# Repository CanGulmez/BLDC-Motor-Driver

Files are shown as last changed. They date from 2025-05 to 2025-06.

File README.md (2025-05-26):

# 2kW BLDC Motor Driver

This project was created for Teknofest - Efficiency Challenge Competition

This repository consists of two part. First is the motor dirver firmware
and second is the KiCAD design. In firmware development, I've used VS Code
and PlatformIO plugin. PCB design is based on STM32F44RE microcontroller
so that the firmware was written with STM32 HAL (Hardware Abstraction Layer)
library. KiCAD design includes both schematic and PCB layout so that it 
can be used directly.

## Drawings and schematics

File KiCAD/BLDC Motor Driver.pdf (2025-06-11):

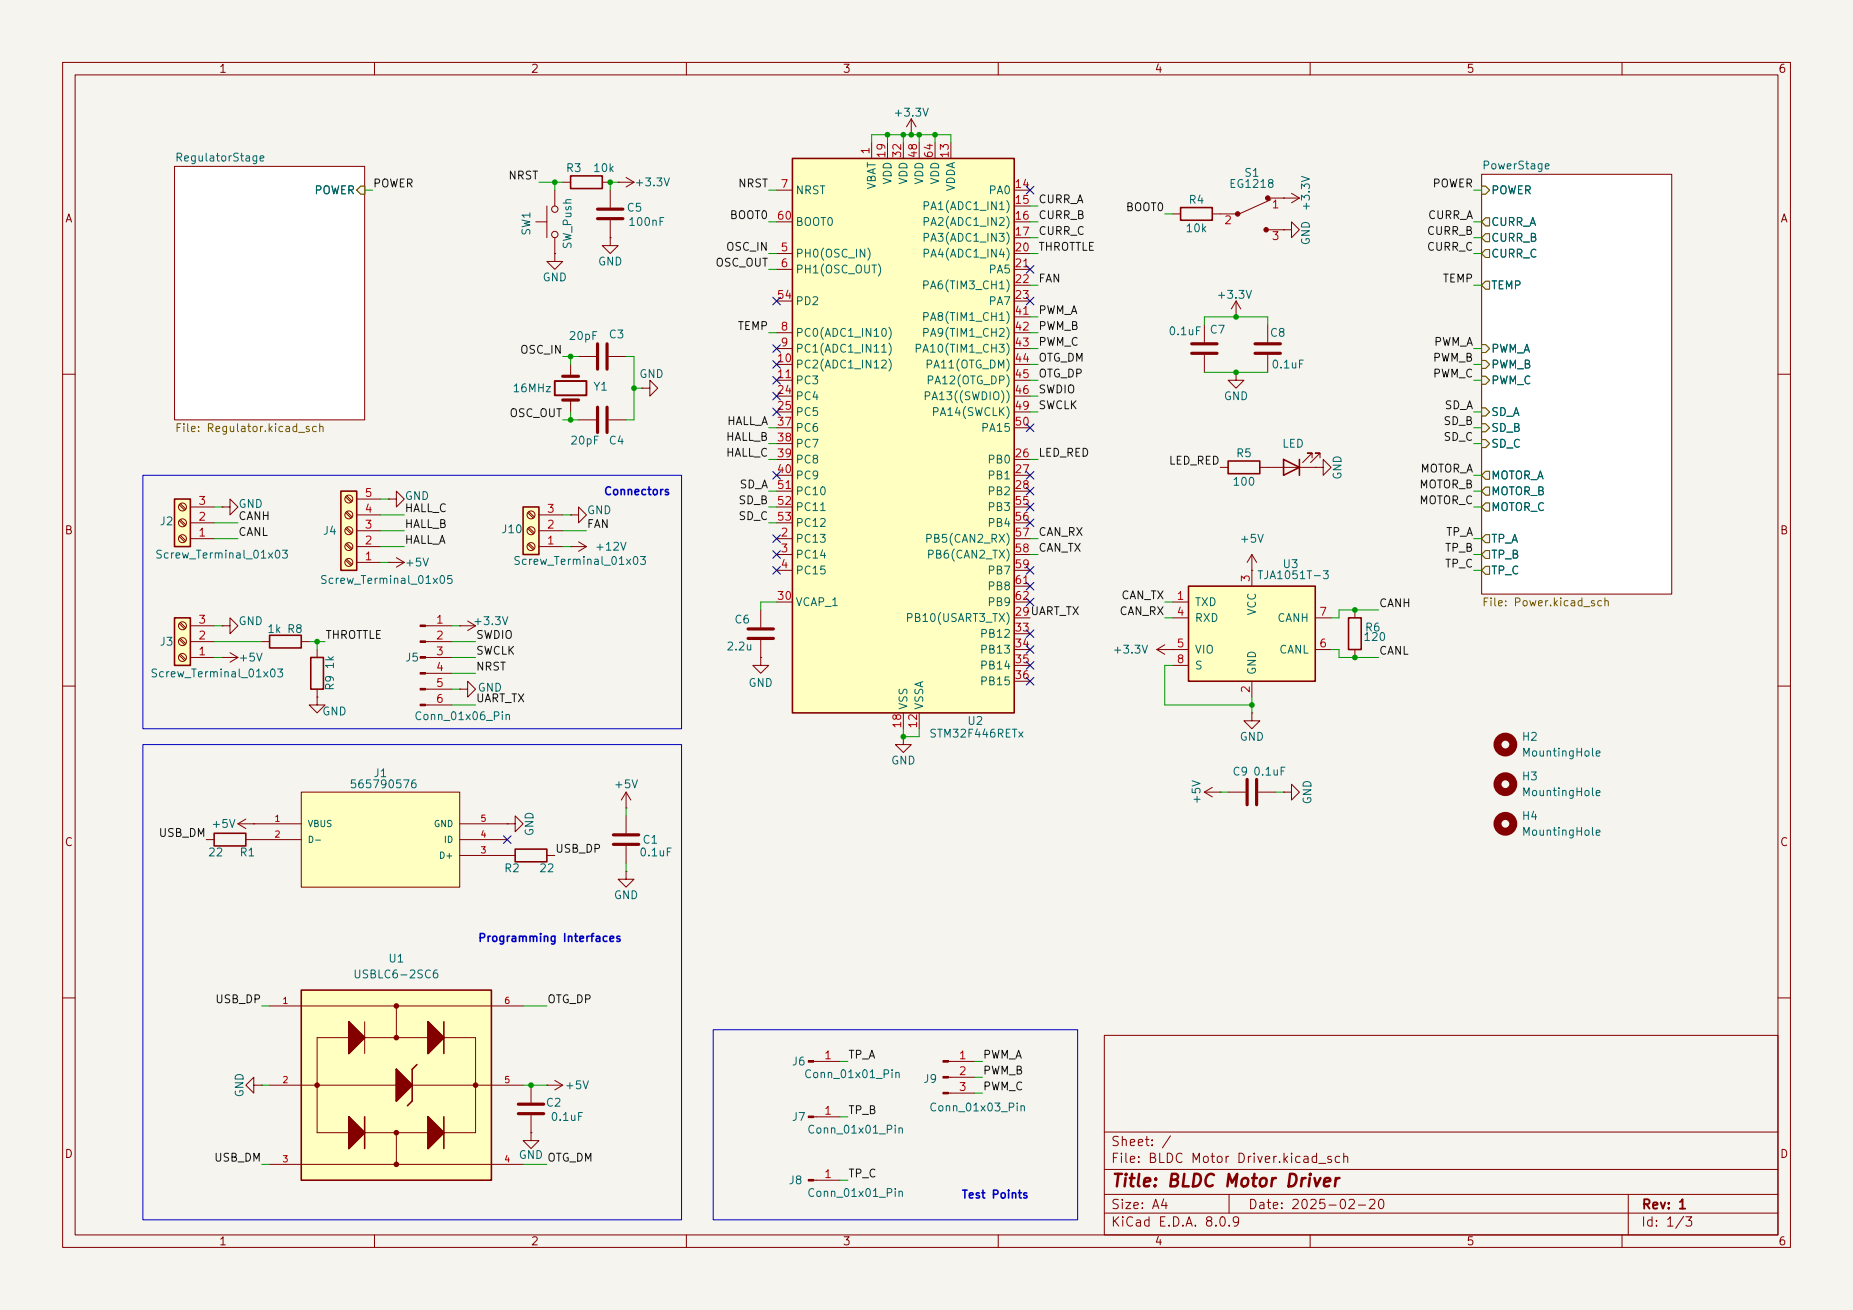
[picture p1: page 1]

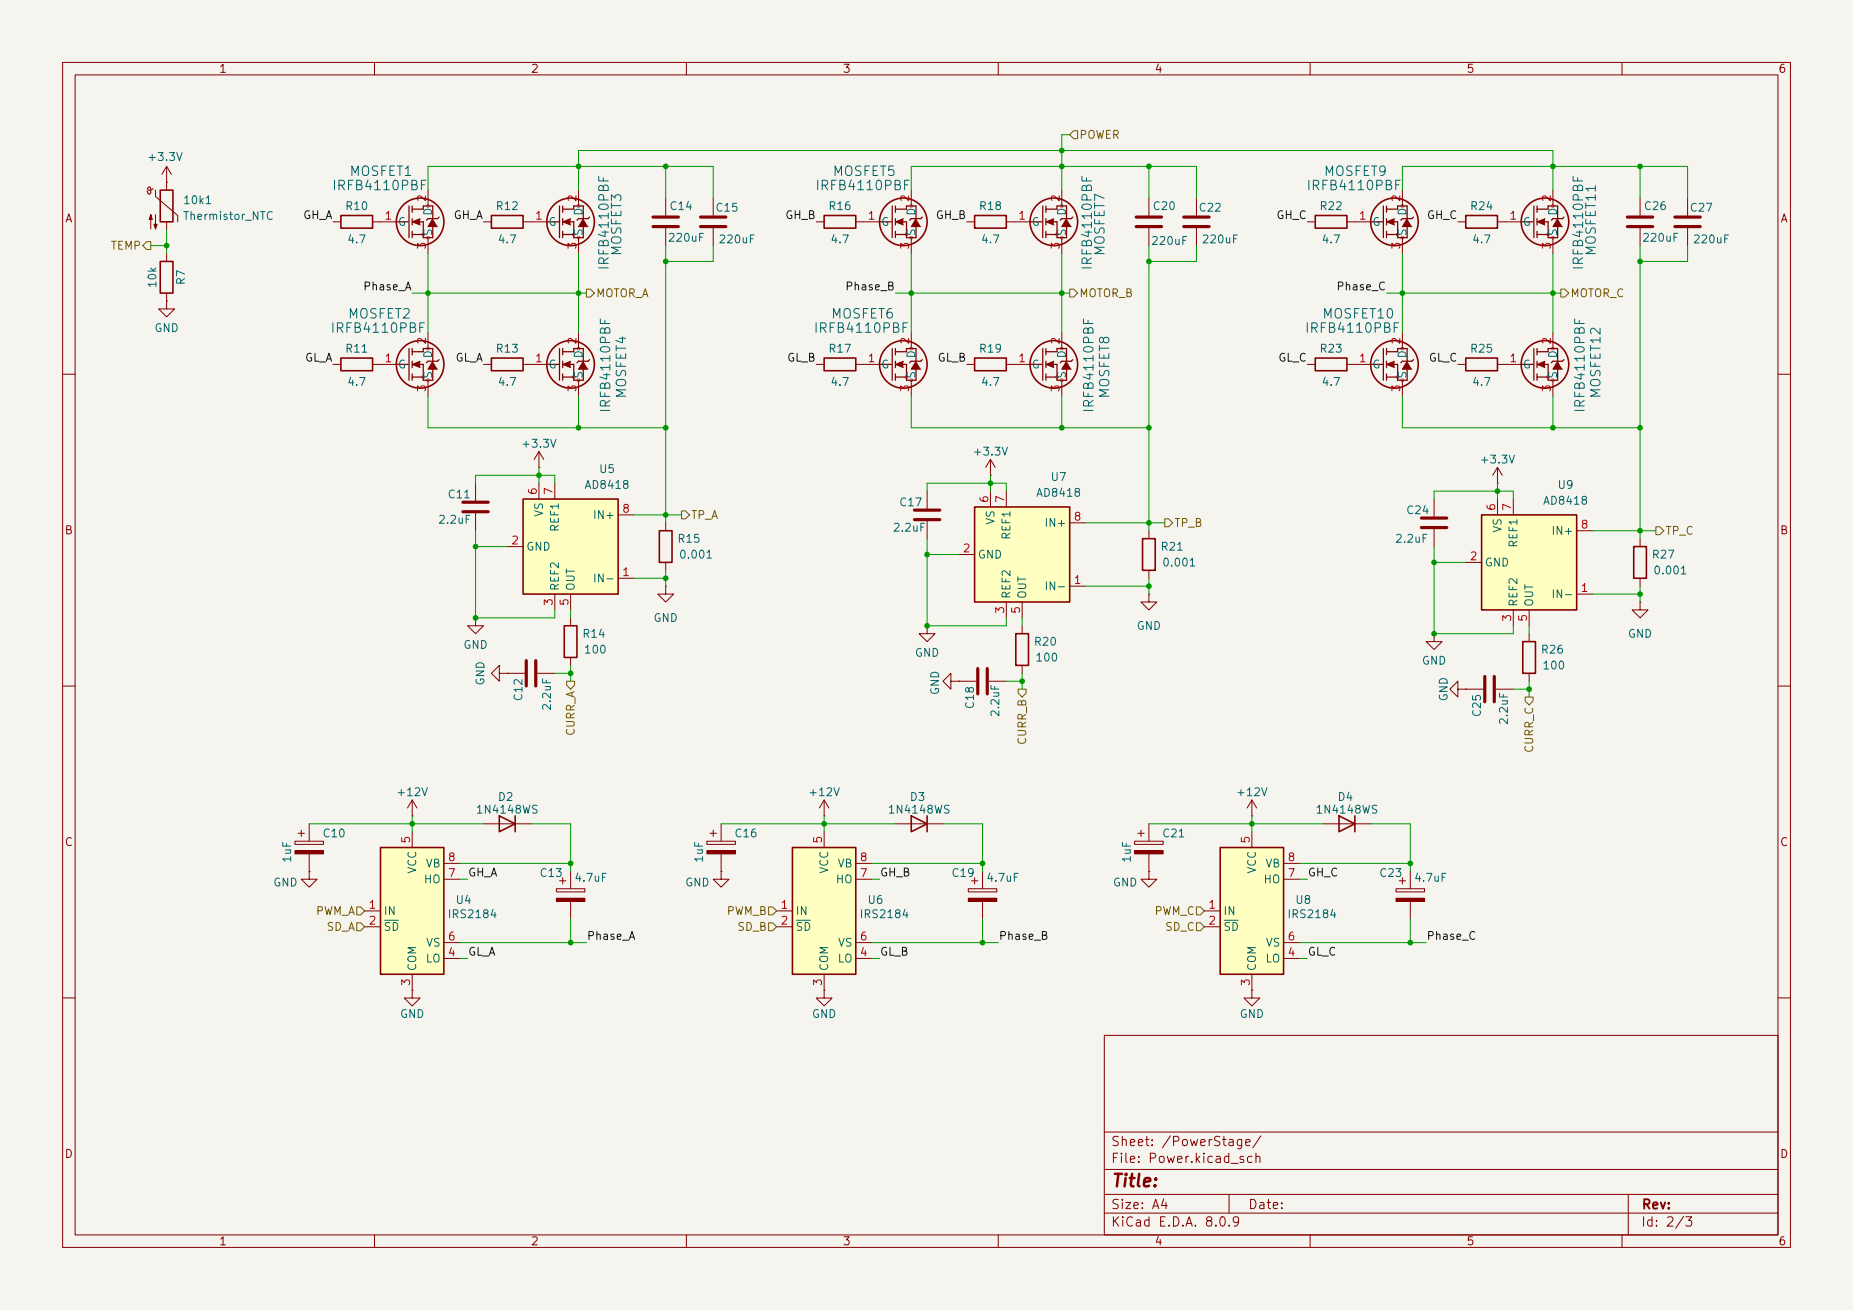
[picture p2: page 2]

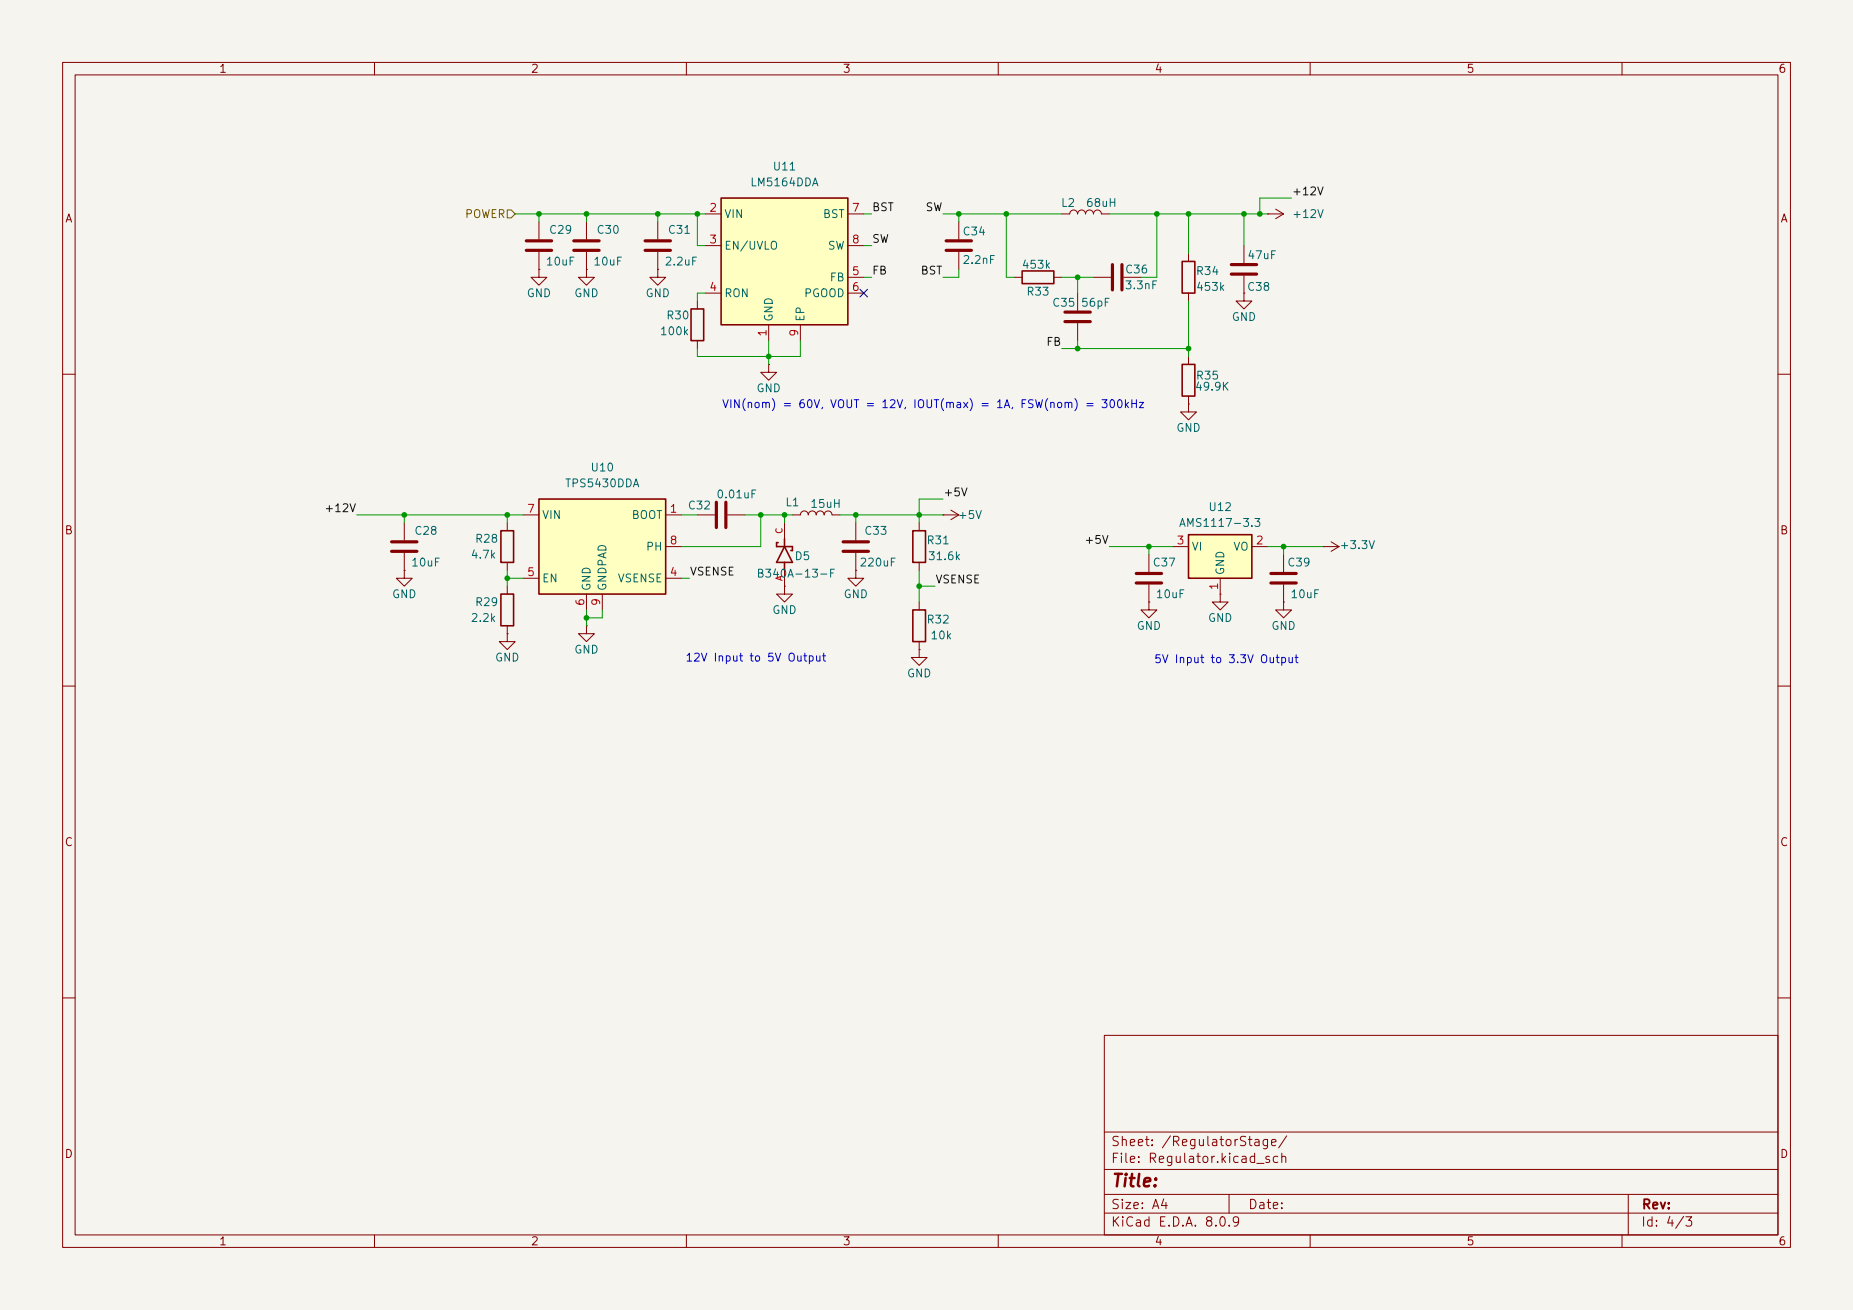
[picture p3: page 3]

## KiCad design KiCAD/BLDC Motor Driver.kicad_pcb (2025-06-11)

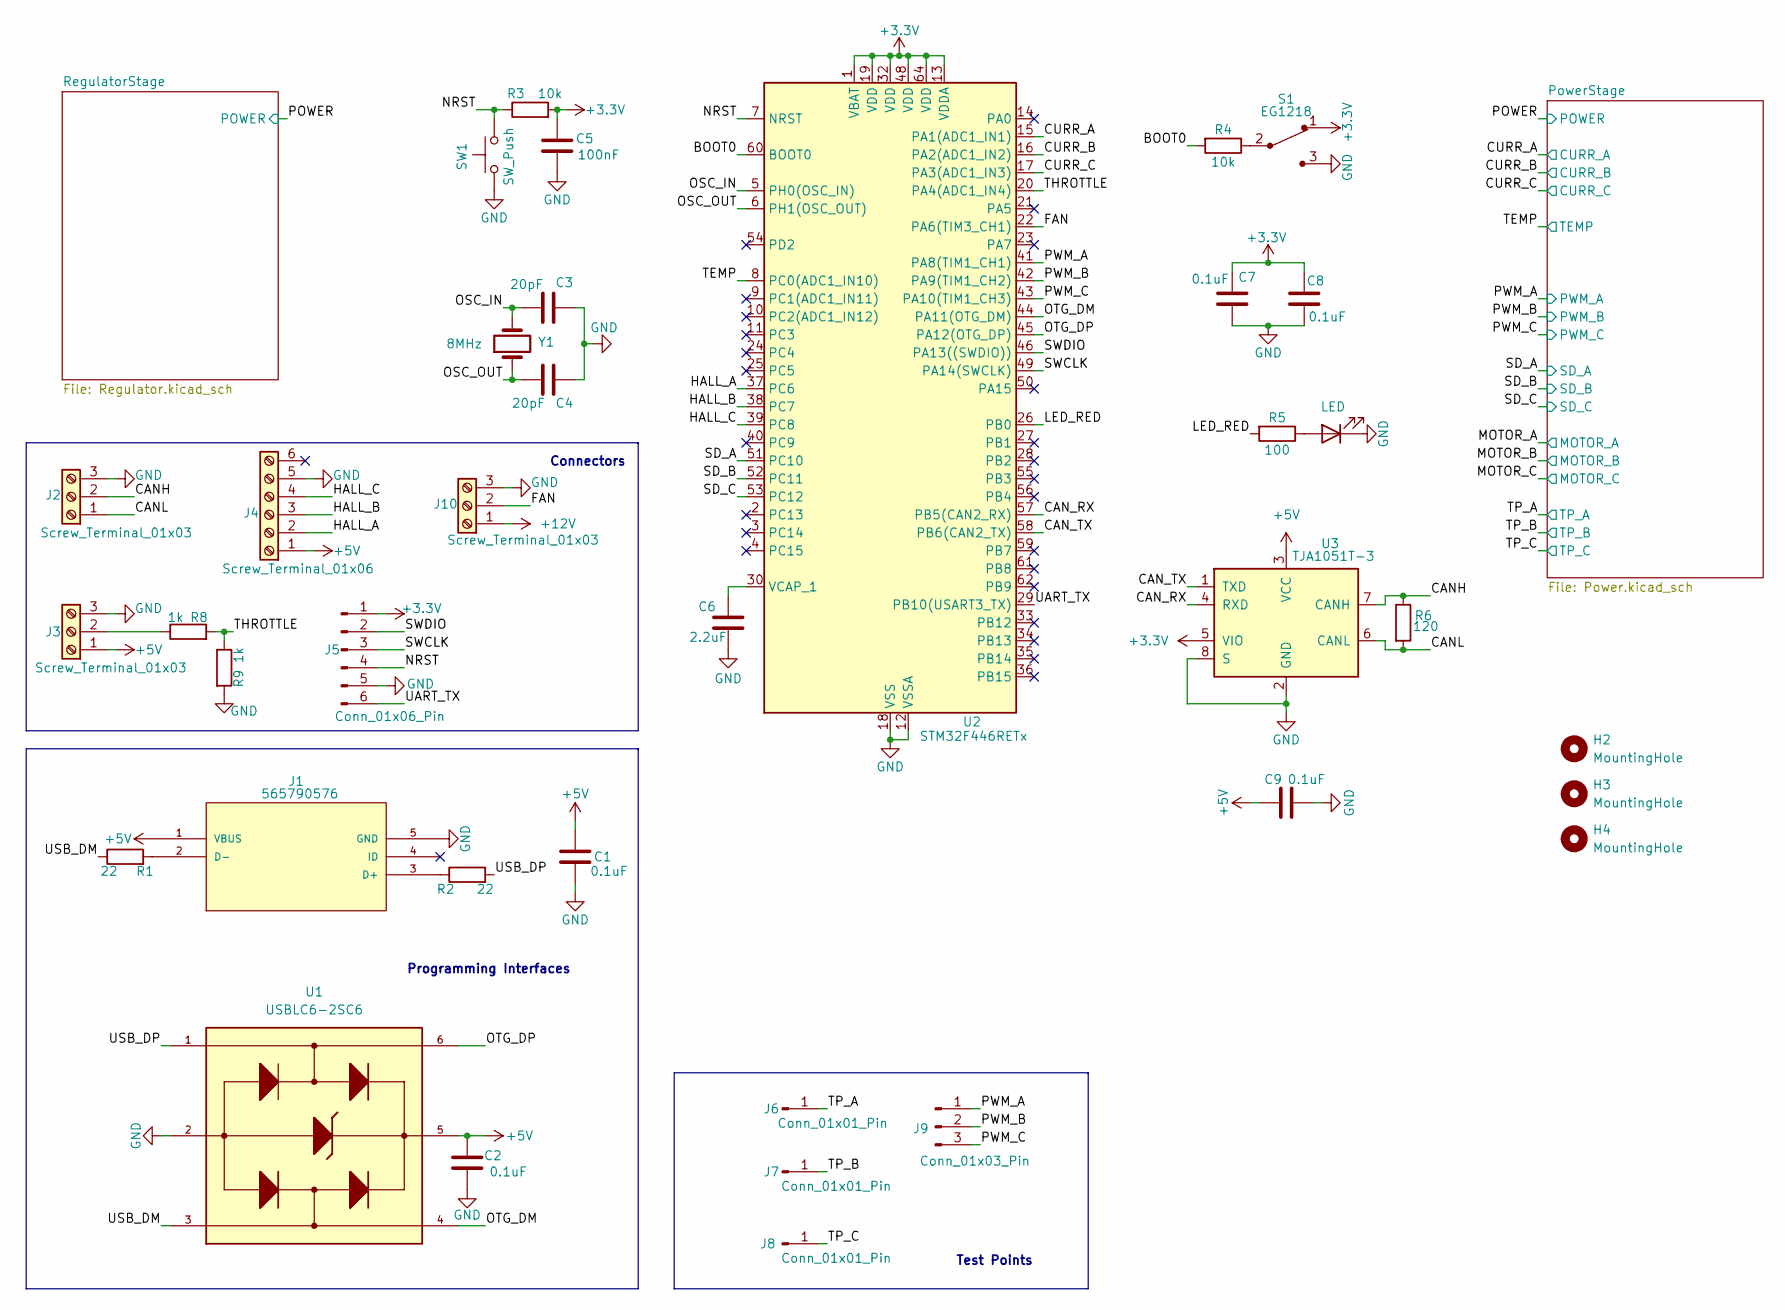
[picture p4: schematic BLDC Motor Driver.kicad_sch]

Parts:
C1, C2, C7, C8, C9: 0.1uF; C_0603_1608Metric
C3, C4: 20pF; C_0603_1608Metric
C5: 100nF; C_0603_1608Metric
C6: 2.2uF; C_0805_2012Metric
D1: LED; LED_0603_1608Metric
H2, H3, H4: MountingHole; MountingHole_3.2mm_M3
J1: 565790576; 56579-0576_MOL; MANUFACTURER_PART_NUMBER 565790576
J2, J3, J10: Screw_Terminal_01x03; TerminalBlock_Phoenix_MKDS-1,5-3-5.08_1x03_P5.08mm_Horizont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
J4: Screw_Terminal_01x06; TerminalBlock_Phoenix_MKDS-1,5-6-5.08_1x06_P5.08mm_Horizont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
J5: Conn_01x06_Pin; PinHeader_1x06_P2.54mm_Vertical
J6, J7, J8: Conn_01x01_Pin; PinHeader_1x01_P2.54mm_Vertical
J9: Conn_01x03_Pin; PinHeader_1x03_P2.54mm_Vertical
R1, R2: 22; R_0603_1608Metric
R3, R4: 10k; R_0603_1608Metric
R5: 100; R_0603_1608Metric
R6: 120; R_0603_1608Metric
R8, R9: 1k; R_0603_1608Metric
S1: EG1218; Switch_Slide_11.6x4mm_EG1218; MPN EG1218; Digi-Key_PN EG1903-ND
SW1: SW_Push; SW_SPST_B3U-1000P
U1: USBLC6-2SC6; SOT95P280X145-6N
U2: STM32F446RETx; LQFP-64_10x10mm_P0.5mm
U3: TJA1051T-3; SOIC-8_3.9x4.9mm_P1.27mm
Y1: 8MHz; Crystal_SMD_5032-2Pin_5.0x3.2mm

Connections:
+3.3V: C5.1, C7.1, C8.1, J5.1, R3.2, S1.1, U2.1 (VBAT), U2.13 (VDDA), U2.19 (VDD), U2.32 (VDD), U2.48 (VDD), U2.64 (VDD), U3.5 (VIO); also elsewhere on the board
+5V: C1.1, C2.1, C9.1, J1.1 (VBUS), J3.1, J4.1, U1.5, U3.3 (VCC); also elsewhere on the board
+12V: J10.1; also elsewhere on the board
/BOOT0: R4.2, U2.60 (BOOT0)
/CANH: J2.2, R6.1, U3.7 (CANH)
/CANL: J2.1, R6.2, U3.6 (CANL)
/CAN_RX: U2.57 (PB5(CAN2_RX)), U3.4 (RXD)
/CAN_TX: U2.58 (PB6(CAN2_TX)), U3.1 (TXD)
/CURR_A: U2.15 (PA1(ADC1_IN1)); also elsewhere on the board
/CURR_B: U2.16 (PA2(ADC1_IN2)); also elsewhere on the board
/CURR_C: U2.17 (PA3(ADC1_IN3)); also elsewhere on the board
/FAN: J10.2, U2.22 (PA6(TIM3_CH1))
/HALL_A: J4.2, U2.37 (PC6)
/HALL_B: J4.3, U2.38 (PC7)
/HALL_C: J4.4, U2.39 (PC8)
/LED_RED: R5.2, U2.26 (PB0)
/NRST: J5.4, R3.1, SW1.2, U2.7 (NRST)
/OSC_IN: C3.1, U2.5 (PH0(OSC_IN)), Y1.2
/OSC_OUT: C4.1, U2.6 (PH1(OSC_OUT)), Y1.1
/OTG_DM: U1.4, U2.44 (PA11(OTG_DM))
/OTG_DP: U1.6, U2.45 (PA12(OTG_DP))
/PWM_A: J9.1, U2.41 (PA8(TIM1_CH1)); also elsewhere on the board
/PWM_B: J9.2, U2.42 (PA9(TIM1_CH2)); also elsewhere on the board
/PWM_C: J9.3, U2.43 (PA10(TIM1_CH3)); also elsewhere on the board
/SD_A: U2.51 (PC10); also elsewhere on the board
/SD_B: U2.52 (PC11); also elsewhere on the board
/SD_C: U2.53 (PC12); also elsewhere on the board
/SWCLK: J5.3, U2.49 (PA14(SWCLK))
/SWDIO: J5.2, U2.46 (PA13((SWDIO)))
/TEMP: U2.8 (PC0(ADC1_IN10)); also elsewhere on the board
/THROTTLE: R8.2, R9.1, U2.20 (PA4(ADC1_IN4))
/TP_A: J6.1; also elsewhere on the board
/TP_B: J7.1; also elsewhere on the board
/TP_C: J8.1; also elsewhere on the board
/UART_TX: J5.6, U2.29 (PB10(USART3_TX))
/USB_DM: R1.1, U1.3
/USB_DP: R2.2, U1.1
GND: C1.2, C2.2, C3.2, C4.2, C5.2, C6.2, C7.2, C8.2, C9.2, D1.1 (K), J1.5 (GND), J2.3, J3.3, J4.5, J5.5, J10.3, R9.2, S1.3, SW1.1, U1.2, U2.12 (VSSA), U2.18 (VSS), U2.31 (VSS), U2.47 (VSS), U2.63 (VSS), U3.2 (GND), U3.8 (S); also elsewhere on the board
unnamed: D1.2 (A), R5.1
unnamed: J1.3 (D+), R2.1
unnamed: J1.2 (D-), R1.2
unnamed: J3.2, R8.1
unnamed: R4.1, S1.2
unnamed: C6.1, U2.30 (VCAP_1)

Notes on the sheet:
Connectors
Test Points
Programming Interfaces

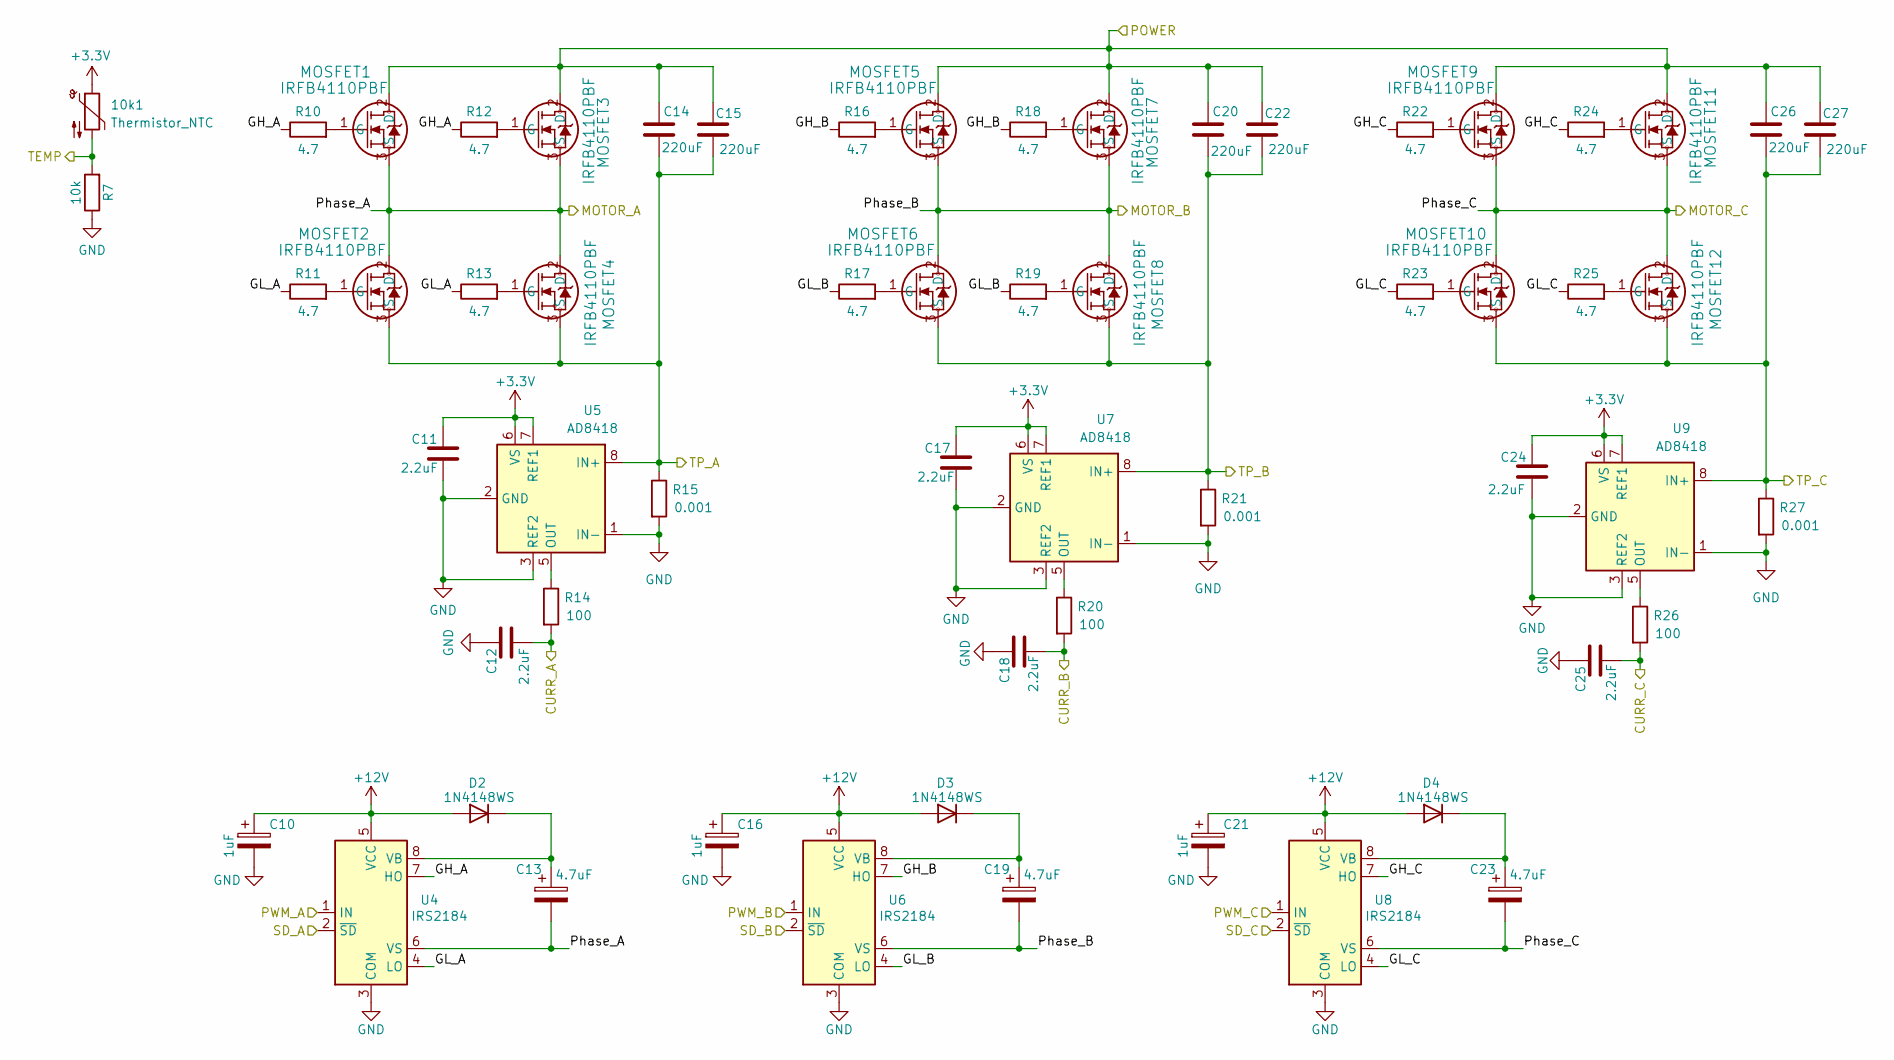
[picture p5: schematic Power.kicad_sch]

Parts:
10k1: Thermistor_NTC; R_0805_2012Metric
C10, C16, C21: 1uF; C_0805_2012Metric
C11, C12, C17, C18, C24, C25: 2.2uF; C_0805_2012Metric
C13, C19, C23: 4.7uF; C_0805_2012Metric
C14, C15, C20, C22, C26, C27: 220uF; C_Elec_10x10.2
D2, D3, D4: 1N4148WS; D_SOD-323
MOSFET1, MOSFET2, MOSFET3, MOSFET4, MOSFET5, MOSFET6, MOSFET7, MOSFET8, MOSFET9, MOSFET10, MOSFET11, MOSFET12: IRFB4110PBF; TO-220-3_Vertical
R7: 10k; R_0603_1608Metric
R10, R11, R12, R13, R16, R17, R18, R19, R22, R23, R24, R25: 4.7; R_0603_1608Metric
R14, R20, R26: 100; R_0603_1608Metric
R15, R21, R27: 0.001; R_2512_6332Metric
U4, U6, U8: IRS2184; SOIC-8_3.9x4.9mm_P1.27mm
U5, U7, U9: AD8418; SOIC-8_3.9x4.9mm_P1.27mm

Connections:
+3.3V: 10k1.1, C11.1, C17.1, C24.1, U5.6 (VS), U5.7 (REF1), U7.6 (VS), U7.7 (REF1), U9.6 (VS), U9.7 (REF1); also elsewhere on the board
+12V: C10.1, C16.1, C21.1, D2.2 (A), D3.2 (A), D4.2 (A), U4.5 (VCC), U6.5 (VCC), U8.5 (VCC); also elsewhere on the board
/CURR_A: C12.2, R14.2; also elsewhere on the board
/CURR_B: C18.2, R20.2; also elsewhere on the board
/CURR_C: C25.2, R26.2; also elsewhere on the board
/MOTOR_A: C13.2, MOSFET1.3 (S), MOSFET2.2 (D), MOSFET3.3 (S), MOSFET4.2 (D), U4.6 (VS)
/MOTOR_B: C19.2, MOSFET5.3 (S), MOSFET6.2 (D), MOSFET7.3 (S), MOSFET8.2 (D), U6.6 (VS)
/MOTOR_C: C23.2, MOSFET9.3 (S), MOSFET10.2 (D), MOSFET11.3 (S), MOSFET12.2 (D), U8.6 (VS)
/POWER: C14.1, C15.1, C20.1, C22.1, C26.1, C27.1, MOSFET1.2 (D), MOSFET3.2 (D), MOSFET5.2 (D), MOSFET7.2 (D), MOSFET9.2 (D), MOSFET11.2 (D); also elsewhere on the board
/PWM_A: U4.1 (IN); also elsewhere on the board
/PWM_B: U6.1 (IN); also elsewhere on the board
/PWM_C: U8.1 (IN); also elsewhere on the board
/PowerStage/GH_A: R10.1, R12.1, U4.7 (HO)
/PowerStage/GH_B: R16.1, R18.1, U6.7 (HO)
/PowerStage/GH_C: R22.1, R24.1, U8.7 (HO)
/PowerStage/GL_A: R11.1, R13.1, U4.4 (LO)
/PowerStage/GL_B: R17.1, R19.1, U6.4 (LO)
/PowerStage/GL_C: R23.1, R25.1, U8.4 (LO)
/SD_A: U4.2 (~SD); also elsewhere on the board
/SD_B: U6.2 (~SD); also elsewhere on the board
/SD_C: U8.2 (~SD); also elsewhere on the board
/TEMP: 10k1.2, R7.2; also elsewhere on the board
/TP_A: C14.2, C15.2, MOSFET2.3 (S), MOSFET4.3 (S), R15.1, U5.8 (IN+); also elsewhere on the board
/TP_B: C20.2, C22.2, MOSFET6.3 (S), MOSFET8.3 (S), R21.1, U7.8 (IN+); also elsewhere on the board
/TP_C: C26.2, C27.2, MOSFET10.3 (S), MOSFET12.3 (S), R27.1, U9.8 (IN+); also elsewhere on the board
GND: C10.2, C11.2, C12.1, C16.2, C17.2, C18.1, C21.2, C24.2, C25.1, R7.1, R15.2, R21.2, R27.2, U4.3 (COM), U5.1 (IN-), U5.2 (GND), U5.3 (REF2), U6.3 (COM), U7.1 (IN-), U7.2 (GND), U7.3 (REF2), U8.3 (COM), U9.1 (IN-), U9.2 (GND), U9.3 (REF2); also elsewhere on the board
unnamed: C13.1, D2.1 (K), U4.8 (VB)
unnamed: C19.1, D3.1 (K), U6.8 (VB)
unnamed: C23.1, D4.1 (K), U8.8 (VB)
unnamed: MOSFET1.1 (G), R10.2
unnamed: MOSFET2.1 (G), R11.2
unnamed: MOSFET3.1 (G), R12.2
unnamed: MOSFET4.1 (G), R13.2
unnamed: MOSFET5.1 (G), R16.2
unnamed: MOSFET6.1 (G), R17.2
unnamed: MOSFET7.1 (G), R18.2
unnamed: MOSFET8.1 (G), R19.2
unnamed: MOSFET9.1 (G), R22.2
unnamed: MOSFET10.1 (G), R23.2
unnamed: MOSFET11.1 (G), R24.2
unnamed: MOSFET12.1 (G), R25.2
unnamed: R14.1, U5.5 (OUT)
unnamed: R20.1, U7.5 (OUT)
unnamed: R26.1, U9.5 (OUT)

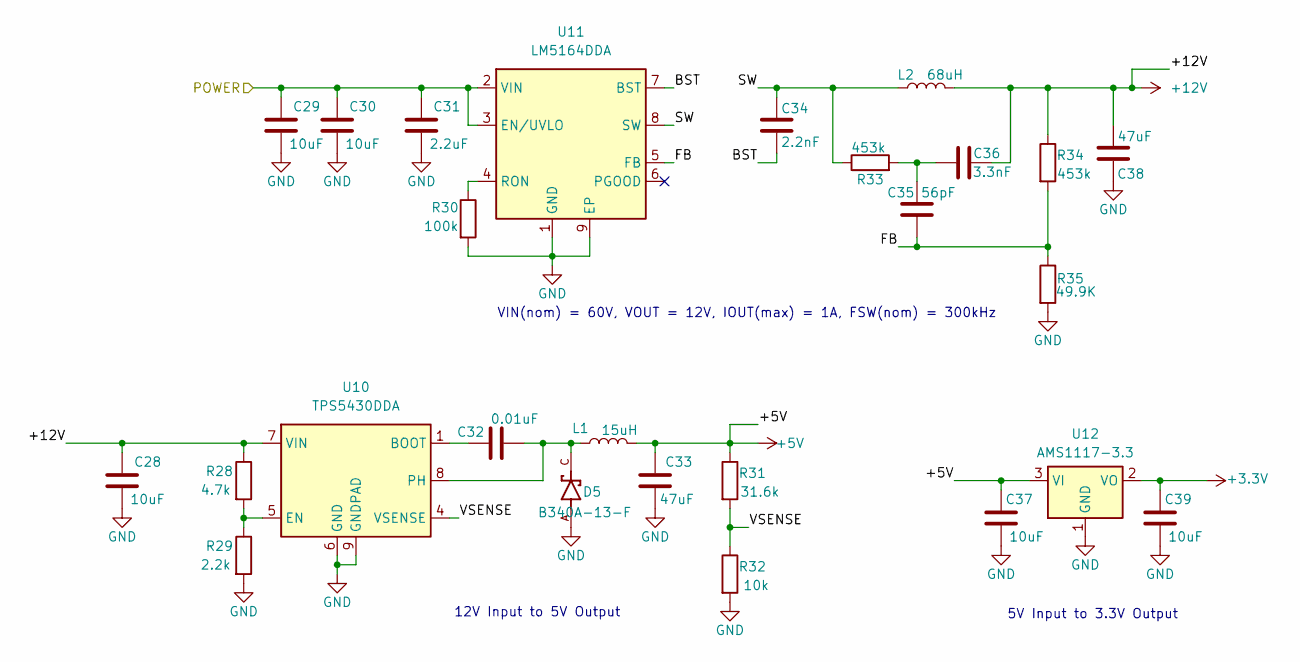
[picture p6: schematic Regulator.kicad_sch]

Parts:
C28, C29, C30, C37, C39: 10uF; C_0805_2012Metric
C31: 2.2uF; C_0805_2012Metric
C32: 0.01uF; C_0402_1005Metric
C33, C38: 47uF; C_Elec_6.3x5.4
C34: 2.2nF; C_0402_1005Metric
C35: 56pF; C_0402_1005Metric
C36: 3.3nF; C_0402_1005Metric
D5: B340A-13-F; DIOM5226X240N; PARTREV 17-2
L1: 15uH; L_0805_2012Metric
L2: 68uH; L_0805_2012Metric
R28: 4.7k; R_0603_1608Metric
R29: 2.2k; R_0603_1608Metric
R30: 100k; R_0603_1608Metric
R31: 31.6k; R_0603_1608Metric
R32: 10k; R_0603_1608Metric
R33, R34: 453k; R_0603_1608Metric
R35: 49.9K; R_0603_1608Metric
U10: TPS5430DDA; TI_SO-PowerPAD-8_ThermalVias
U11: LM5164DDA; HSOP-8-1EP_3.9x4.9mm_P1.27mm_EP2.41x3.1mm_ThermalVias
U12: AMS1117-3.3; SOT-223-3_TabPin2

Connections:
+3.3V: C39.1, U12.2 (VO); also elsewhere on the board
+5V: C33.1, C37.1, L1.2, R31.1, U12.3 (VI); also elsewhere on the board
+12V: C28.1, C36.2, C38.2, L2.2, R28.1, R34.1, U10.7 (VIN); also elsewhere on the board
/POWER: C29.1, C30.1, C31.1, U11.2 (VIN), U11.3 (EN/UVLO); also elsewhere on the board
/RegulatorStage/BST: C34.2, U11.7 (BST)
/RegulatorStage/FB: C35.1, R34.2, R35.1, U11.5 (FB)
/RegulatorStage/SW: C34.1, L2.1, R33.1, U11.8 (SW)
/RegulatorStage/VSENSE: R31.2, R32.1, U10.4 (VSENSE)
GND: C28.2, C29.2, C30.2, C31.2, C33.2, C37.2, C38.1, C39.2, D5.A, R29.2, R30.2, R32.2, R35.2, U10.6 (GND), U10.9 (GNDPAD), U11.1 (GND), U11.9 (EP), U12.1 (GND); also elsewhere on the board
unnamed: C35.2, C36.1, R33.2
unnamed: C32.1, U10.1 (BOOT)
unnamed: R28.2, R29.1, U10.5 (EN)
unnamed: C32.2, D5.C, L1.1, U10.8 (PH)
unnamed: R30.1, U11.4 (RON)

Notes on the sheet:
VIN(nom) = 60V, VOUT = 12V, IOUT(max) = 1A, FSW(nom) = 300kHz
5V Input to 3.3V Output
12V Input to 5V Output

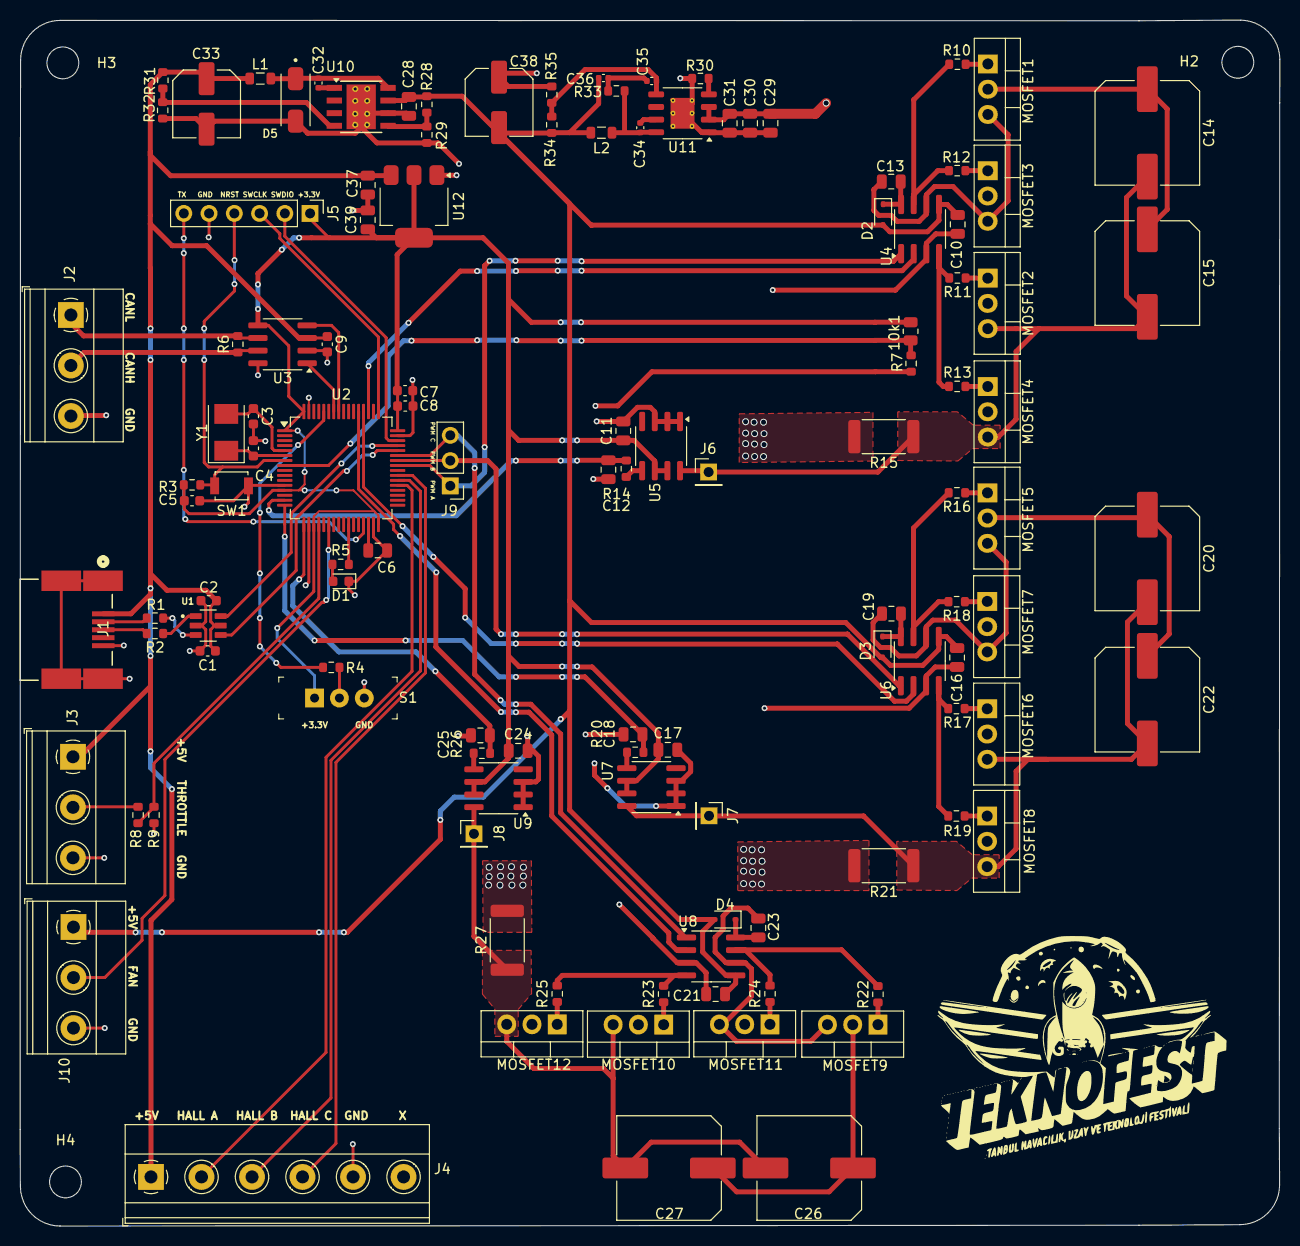
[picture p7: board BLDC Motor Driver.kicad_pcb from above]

Board: 2 copper layers, 126.7 x 121.3 mm, 122 parts (0 on the bottom side), 81 nets.

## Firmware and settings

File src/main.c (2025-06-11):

/**
 * BLDC Motor Driver 
 */

#include "bldc_motor_driver.h"

/* Initial motor configurations and variables that set by HAL */

volatile bool_t failure       = FALSE;
volatile char state           = BLDC_STATE_OFF;
uint32_t buffer[5]            = {0};
bldc_mdata1_t mdata1          = {0};
bldc_mdata2_t mdata2          = {0};
uint32_t txMailbox            = {0};

/* These variables will be changed constantly so that they are defined 
   as 'volatile'. This will prevent the compiler from optimizing them. */

volatile double temp;                                
volatile double currA, currB, currC, maxCurr;                  
volatile double throttle;                              
volatile double clarkeA, clarkeB;                       
volatile double actParkD, actParkQ;
volatile double refParkD, refParkQ;
volatile char hallA, hallB, hallC, hallPos, sector;   
volatile uint32_t currStamp, diffStamp;                
static uint32_t lastStamp, lastSector;               
volatile double eRPM, mRPM, actSpeed, refSpeed;
volatile double posDeg, posRad;                       
volatile double actTorque, refTorque;
volatile double speedErr, parkDErr, parkQErr;                  
static double speedIn, parkDIn, parkQIn;
volatile double Ki, Kp;
volatile double VParkD, VParkQ, VClarkeA, VClarkeB, Va, Vb, Vc;
volatile double VMax, VMin, VOffset, dutyA, dutyB, dutyC;
volatile double driverPower, inputPower, outputPower, efficiency;

void main(void)
{
   HAL_Init(); 

   /* Enable the peripheral clocks */
   __HAL_RCC_GPIOA_CLK_ENABLE();
   __HAL_RCC_GPIOB_CLK_ENABLE();
   __HAL_RCC_GPIOC_CLK_ENABLE();
   __HAL_RCC_ADC1_CLK_ENABLE();
   __HAL_RCC_DMA1_CLK_ENABLE();
   __HAL_RCC_TIM2_CLK_ENABLE();
   __HAL_RCC_TIM3_CLK_ENABLE();
   __HAL_RCC_TIM1_CLK_ENABLE();
   __HAL_RCC_CAN1_CLK_ENABLE();
   __HAL_RCC_CAN2_CLK_ENABLE();
   __HAL_RCC_SYSCFG_CLK_ENABLE();
 
   /* Initialize and configure peripherals */
   bldc_perip_oscillator();
   bldc_perip_clock();
   bldc_perip_timer();
   bldc_perip_analog();
   bldc_perip_digital();
   bldc_perip_serial();
   bldc_perip_comm();

   /* Set the initial conditon for PWMs */
   __HAL_TIM_SET_COMPARE(&htim1, TIM_CHANNEL_1, 0.0);
   __HAL_TIM_SET_COMPARE(&htim1, TIM_CHANNEL_2, 0.0);
   __HAL_TIM_SET_COMPARE(&htim1, TIM_CHANNEL_3, 0.0);
   
   /* Start the peripherals */
   HAL_TIM_Base_Start(&htim2);
   HAL_TIM_Base_Start(&htim3);
   HAL_TIM_PWM_Start(&htim1, TIM_CHANNEL_1);
   HAL_TIM_PWM_Start(&htim1, TIM_CHANNEL_2);
   HAL_TIM_PWM_Start(&htim1, TIM_CHANNEL_3);
   HAL_ADC_Start_DMA(&hadc1, &buffer, 5);
   HAL_CAN_Start(&hcan2);
   HAL_CAN_ActivateNotification(&hcan2, CAN_IT_RX_FIFO0_MSG_PENDING);
   
   /* Make the default settings until any failure condition occurs */
   HAL_GPIO_WritePin(GPIOB, GPIO_PIN_0, GPIO_PIN_SET);
   HAL_GPIO_WritePin(GPIOC, GPIO_PIN_10, GPIO_PIN_SET);
   HAL_GPIO_WritePin(GPIOC, GPIO_PIN_11, GPIO_PIN_SET);
   HAL_GPIO_WritePin(GPIOC, GPIO_PIN_12, GPIO_PIN_SET);
   state = BLDC_STATE_ON;

   while (1) {

      /* Pack the required motor data to send over CAN */
      mdata1.frame = (uint8_t) BLDC_FRAME_1;
      mdata1.state = (uint8_t) state;
      mdata1.temp = (uint8_t) temp;
      mdata1.currA = (uint8_t) currA;
      mdata1.currB = (uint8_t) currB;
      mdata1.currC = (uint8_t) currC;
      mdata1.speed = (uint8_t) actSpeed;
      mdata1.torque = (uint8_t) actTorque;
      mdata2.RPM = (uint8_t) mRPM;
      maxCurr = fmax(fabs(currA), fmax(fabs(currB), fabs(currC)));
      mdata2.inputPower = (uint8_t) (VBUS * maxCurr / 1000.0); 
      mdata2.driverPower = (uint8_t) (pow(maxCurr, 2) * RDS_ON + 0.5 * VBUS * 
         maxCurr * (T_RISE + T_FALL) * 10000.0 + QGATE * VGS * 10000) / 1000.0;
      mdata2.outputPower = (uint8_t) (mdata2.inputPower - mdata2.driverPower);
      mdata2.efficiency = (uint8_t) ((mdata2.outputPower / mdata2.inputPower));
      mdata2.NA[0] = 0;
      mdata2.NA[1] = 0;
      mdata2.NA[2] = 0;

      /* Send the motor data to vehicle control system */
      txHeader.StdId = MOTOR_ID;
      txHeader.ExtId = 0;
      txHeader.IDE = CAN_ID_STD;
      txHeader.RTR = CAN_RTR_DATA;
      txHeader.DLC = sizeof(bldc_mdata1_t);
      txHeader.TransmitGlobalTime = DISABLE;
      HAL_CAN_AddTxMessage(&hcan2, &txHeader, (uint8_t*) &mdata1, &txMailbox);
      HAL_CAN_AddTxMessage(&hcan2, &txHeader, (uint8_t*) &mdata2, &txMailbox);

      /* Stop the motor driver due to detected shutdown state */
      if (failure == TRUE) {
         state = BLDC_STATE_FAILURE;
         speedIn = 0;
         parkDIn = 0; 
         parkQIn = 0;
         HAL_GPIO_WritePin(GPIOB, GPIO_PIN_0, GPIO_PIN_RESET);
         HAL_GPIO_WritePin(GPIOC, GPIO_PIN_10, GPIO_PIN_RESET);
         HAL_GPIO_WritePin(GPIOC, GPIO_PIN_11, GPIO_PIN_RESET);
         HAL_GPIO_WritePin(GPIOC, GPIO_PIN_12, GPIO_PIN_RESET);
         HAL_TIM_Base_Stop(&htim2);
         HAL_TIM_Base_Stop(&htim3);
         HAL_TIM_PWM_Stop(&htim1, TIM_CHANNEL_1);
         HAL_TIM_PWM_Stop(&htim1, TIM_CHANNEL_2);
         HAL_TIM_PWM_Stop(&htim1, TIM_CHANNEL_3);
         HAL_CAN_Stop(&hcan2);
         HAL_ADC_Stop_DMA(&hadc1); 
      }
      
      /* Delay for a while... */
      HAL_Delay(1000);
   }
}

void HAL_ADC_ConvCpltCallback(ADC_HandleTypeDef* hadc)
{
   if (hadc->Instance == ADC1) {
      
      /* Convert the ADC buffer to corresponding data */
      currA = CURR(buffer[0]);
      currB = CURR(buffer[1]);
      currC = CURR(buffer[2]);
      throttle = THROTTLE(buffer[3]);
      temp = TEMP(buffer[4]);

      /* Calculate the position in radians and degrees */
      posDeg = ((lastSector - 1) * 60.0) + 
         (((COUNTER(&htim3) - currStamp) / diffStamp) * 60.0);
      if (posDeg > 360.0)
         posDeg -= 360.0;
      posRad = RAD(posDeg);

      /* Apply Clarke and Park transformations onto phase currents */
      clarkeA = (1.0 / 3.0) * (2 * currA - currB - currC);
      clarkeB = (sqrt(3.0) / 3.0) * (currB - currC);
      actParkD = clarkeA * cos(posRad) + clarkeB * sin(posRad);
      actParkQ = -clarkeA * sin(posRad) + clarkeB * cos(posRad);
 
      /* Indicate the referance speed and actual torque */
      refSpeed = MAX_SPEED * throttle;
      actTorque = actParkQ * TORQUE_CONST;

      Kp = 0.1;
      Ki = 0.02;
      speedIn = 0.0;
      speedErr = refSpeed - actSpeed;
      speedIn += speedErr;
      if (speedIn > MAX_SPEED_INTEGRAL) speedIn = MAX_SPEED_INTEGRAL;
      if (speedIn < -MAX_SPEED_INTEGRAL) speedIn = -MAX_SPEED_INTEGRAL;
      refTorque = Kp * speedErr + Ki * speedIn;
      if (refTorque > MAX_TORQUE) refTorque = MAX_TORQUE;
      if (refTorque < -MAX_TORQUE) refTorque = -MAX_TORQUE;

      refParkD = 0.0;
      refParkQ = refTorque / TORQUE_CONST;
 
      Kp = 2.0;
      Ki = 100.0;
      parkDErr = refParkD - actParkD;
      parkQErr = refParkQ - actParkQ;
      parkDIn += parkDErr;
      parkQIn += parkQErr;
      if (parkDIn > MAX_CURRENT_INTEGRAL) parkDIn = MAX_CURRENT_INTEGRAL;
      if (parkDIn < -MAX_CURRENT_INTEGRAL) parkDIn = -MAX_CURRENT_INTEGRAL;
      if (parkQIn > MAX_CURRENT_INTEGRAL) parkQIn = MAX_CURRENT_INTEGRAL;
      if (parkQIn < -MAX_CURRENT_INTEGRAL) parkQIn = -MAX_CURRENT_INTEGRAL;
      VParkD = Kp * parkDErr + Ki * parkDIn;
      VParkQ = Kp * parkQErr + Ki * parkQIn;

      if (VParkD > MAX_VOLTAGE) VParkD = MAX_VOLTAGE;
      if (VParkD < MAX_VOLTAGE) VParkD = -MAX_VOLTAGE;
      if (VParkQ > MAX_VOLTAGE) VParkQ = MAX_VOLTAGE;
      if (VParkQ < MAX_VOLTAGE) VParkQ = -MAX_VOLTAGE;

      /* Apply inverse Clarke/Park transformations */
      VClarkeA = VParkD * cos(posRad) - VParkQ * sin(posRad);
      VClarkeB = VParkD * sin(posRad) + VParkQ * cos(posRad);
      Va = VClarkeA;
      Vb = -0.5 * VClarkeA + (sqrt(3.0) / 2.0) * VClarkeB;
      Vc = -0.5 * VClarkeA - (sqrt(3.0) / 2.0) * VClarkeB;

      /* Set the voltages which will be applied */
      VMax = fmax(Va, fmax(Vb, Vc));
      VMin = fmin(Va, fmin(Vb, Vc));
      VOffset = 0.5 * (VMax + VMin);
      Va -= VOffset;
      Vb -= VOffset;
      Vc -= VOffset; 

      /* Determine the phase duty cycles using phase voltages */
      dutyA = 0.5 + (Va / VBUS);
      dutyB = 0.5 + (Vb / VBUS);
      dutyC = 0.5 + (Vc / VBUS);      
      if (dutyA > 1.0) dutyA = 1.0;
      if (dutyA < 0.0) dutyA = 0.0;
      if (dutyB > 1.0) dutyB = 1.0;
      if (dutyB < 0.0) dutyB = 0.0;
      if (dutyC > 1.0) dutyC = 1.0;
      if (dutyC < 0.0) dutyC = 0.0;

      /* Update the duty cycles of timer for three PWM channels  */
      __HAL_TIM_SET_COMPARE(&htim1, TIM_CHANNEL_1, dutyA * 
         (htim1.Init.Period + 1));
      __HAL_TIM_SET_COMPARE(&htim1, TIM_CHANNEL_2, dutyB * 
         (htim1.Init.Period + 1));
      __HAL_TIM_SET_COMPARE(&htim1, TIM_CHANNEL_3, dutyC * 
         (htim1.Init.Period + 1));

      /* Check the possible shutdown state */
      if (temp > MAX_TEMP || currA > MAX_CURR || 
          currB > MAX_CURR || currC > MAX_CURR)
         failure = TRUE;
   }
}

void EXTI9_5_IRQHandler(void)
{
   /* IRQs for all hall sensors (PC6, PC7, PC8) */
   HAL_GPIO_EXTI_IRQHandler(GPIO_PIN_6);
   HAL_GPIO_EXTI_IRQHandler(GPIO_PIN_7);
   HAL_GPIO_EXTI_IRQHandler(GPIO_PIN_8);
}
 
void HAL_GPIO_EXTI_Callback(uint16_t GPIO_Pin)
{
   if (GPIO_Pin == GPIO_PIN_6 || GPIO_Pin == GPIO_PIN_7 || 
       GPIO_Pin == GPIO_PIN_8) {

      /* Read the Hall sensors and then map the position */
      hallA = HAL_GPIO_ReadPin(GPIOC, GPIO_PIN_6);
      hallB = HAL_GPIO_ReadPin(GPIOC, GPIO_PIN_7);
      hallC = HAL_GPIO_ReadPin(GPIOC, GPIO_PIN_8);
      hallPos = (hallA << 2) | (hallB << 1) | hallC;
      lastSector = SECTOR(hallPos);

      /* Make some calculations using the hall transations */
      currStamp = COUNTER(&htim3);
      diffStamp = currStamp - lastStamp;
      lastStamp = currStamp;
      eRPM = 60.0 / (6.0 * diffStamp / 1e6);
      mRPM = eRPM / POLE_PAIRS;
      actSpeed = SPEED(mRPM);
   }
}
 
void SysTick_Handler(void) 
{
   HAL_IncTick();
}

void HAL_CAN_RxFifo0MsgPendingCallback(CAN_HandleTypeDef *hcan) 
{
   if (hcan->Instance == CAN2) {

      /* Receive the message from EV control system over CAN */
      CAN_RxHeaderTypeDef RxHeader;
      uint8_t RxData[8];
   }
}

void CAN2_RX0_IRQHandler(void) 
{
   HAL_CAN_IRQHandler(&hcan2);
}

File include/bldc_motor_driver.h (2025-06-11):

/**
 * BLDC Motor Driver
 */

#include <math.h>
#include <stm32f4xx_hal.h>

/* User-defined global constants */

#define MOTOR_ID              0x01

#define M_PI                  3.14159265358979323846
#define A                     0.001129148
#define B                     0.000234125
#define C                     0.0000000876741
#define FIX_R                 10000.0
#define SHUNT_R               0.001
#define GAIN                  20

#define MAX_TEMP              100.0
#define MAX_CURR              100.0
#define MAX_SPEED             100.0             /* km/h */
#define MAX_TORQUE            100.0
#define MAX_VOLTAGE           100.0
#define MAX_SPEED_INTEGRAL    50.0
#define MAX_CURRENT_INTEGRAL  50.0
#define MAX_TORQUE_INTEGRAL   50.0
 
#define WHEEL_RADIUS          43.18
#define GEAR_RATIO            1.0
#define TORQUE_CONST          1.0
#define VBUS                  60.0
#define RDS_ON                pow(3.7, -3)
#define T_RISE                pow(40, -9)
#define T_FALL                pow(70, -9)
#define VGS                   10.0
#define QGATE                 pow(260, -9)
#define POLE_PAIRS            15
#define PWM_PERIOD            1 / 10000         /* 100us */

#define BLDC_ROTOR_POS_1      0b001             /* 0 to 60 */
#define BLDC_ROTOR_POS_2      0b011             /* 60 to 120 */
#define BLDC_ROTOR_POS_3      0b010             /* 120 to 180 */
#define BLDC_ROTOR_POS_4      0b110             /* 180 to 240 */
#define BLDC_ROTOR_POS_5      0b100             /* 240 to 300 */
#define BLDC_ROTOR_POS_6      0b101             /* 300 to 360 */

#define BLDC_STATE_OFF        0x00
#define BLDC_STATE_ON         0x01
#define BLDC_STATE_FAILURE    0x02

#define BLDC_FRAME_1          0x01
#define BLDC_FRAME_2          0x02

#define DEG(rad)              (rad * 180.0 / M_PI)
#define RAD(deg)              (deg * M_PI / 180.0)
#define VOLT(x)               (x / 4095.0 * 3.3)
#define THROTTLE(x)           (x)                  /* 0.0 - 1.0 */
#define R_NTC(x)              ((VOLT(x) * FIX_R) / (3.3 - VOLT(x)))
#define TEMP(x)               (1.0 / (A + B * log(R_NTC(x)) + C * \
                               pow(log(R_NTC(x)), 3)) - 273.15)
#define CURR(x)               (VOLT(x) / 20 / SHUNT_R)
#define SECTOR(x)             (x)                  /* 1-6 */
#define COUNTER(x)            (__HAL_TIM_GET_COUNTER(x))
#define SPEED(x)              (2.0 * M_PI * WHEEL_RADIUS * x / 60.0 * 3.6) /* km/h */

/* User-defined peripheral configurations */

RCC_OscInitTypeDef iosc;
RCC_ClkInitTypeDef iclk;
GPIO_InitTypeDef igpio;
TIM_HandleTypeDef htim2, htim3, htim1;
TIM_MasterConfigTypeDef sMasterConfig;
TIM_OC_InitTypeDef sConfigOC;
ADC_HandleTypeDef hadc1;
ADC_ChannelConfTypeDef sConfig;
DMA_HandleTypeDef hdma_adc1;
UART_HandleTypeDef huart3;
CAN_HandleTypeDef hcan2;
CAN_TxHeaderTypeDef txHeader;
CAN_RxHeaderTypeDef rxHeader;
CAN_FilterTypeDef filterConfig;

/* User-defined enumerations and structures */

typedef enum {
   FALSE, 
   TRUE
} bool_t;

typedef struct {
   uint8_t frame;
   uint8_t state;
   uint8_t temp;
   uint8_t currA;
   uint8_t currB;
   uint8_t currC;
   uint8_t speed;
   uint8_t torque;
} bldc_mdata1_t;
 
typedef struct {
   uint8_t frame;
   uint8_t RPM;
   uint8_t inputPower;
   uint8_t driverPower;
   uint8_t outputPower;
   uint8_t efficiency;
   uint8_t NA[2];
} bldc_mdata2_t;
 
